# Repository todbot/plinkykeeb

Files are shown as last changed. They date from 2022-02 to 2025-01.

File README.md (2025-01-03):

# plinkykeeb

Simple MIDI controller using KB2040 and computer key switches, in Cherry MX or Kailh Choc versions

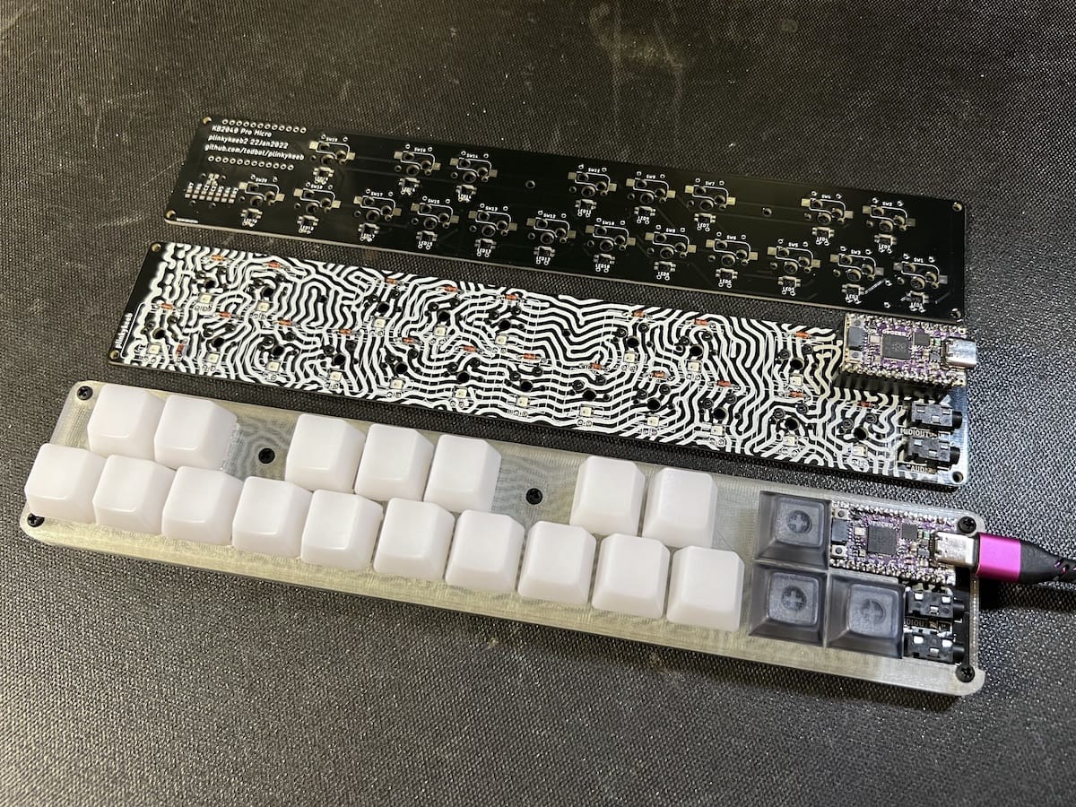
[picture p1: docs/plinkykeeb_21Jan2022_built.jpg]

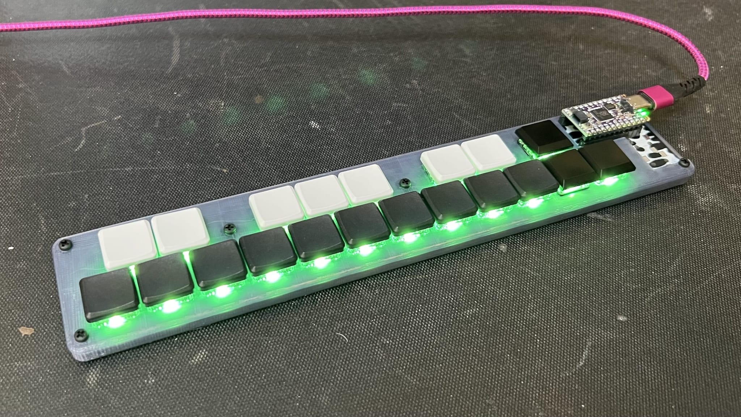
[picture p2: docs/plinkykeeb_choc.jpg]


Also see: https://twitter.com/todbot/status/1492324272714366980__

And this demo video:

https://user-images.githubusercontent.com/274093/153778157-13a1d3d5-e82a-40dc-8635-7ddb3dfab898.mp4

Comparison in heights:
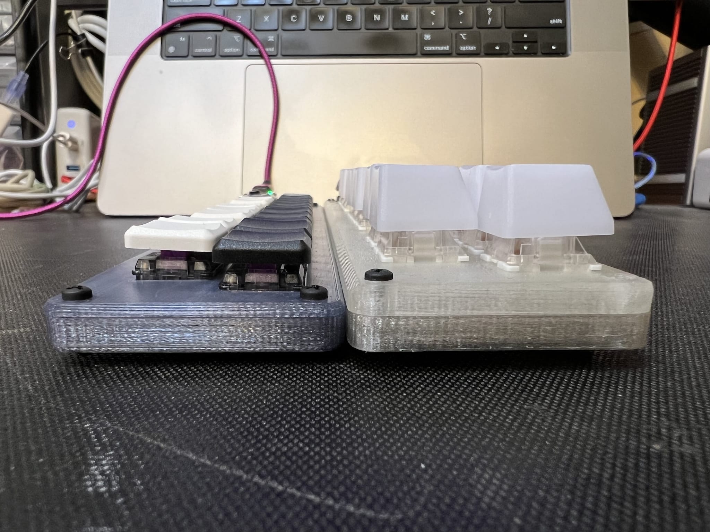
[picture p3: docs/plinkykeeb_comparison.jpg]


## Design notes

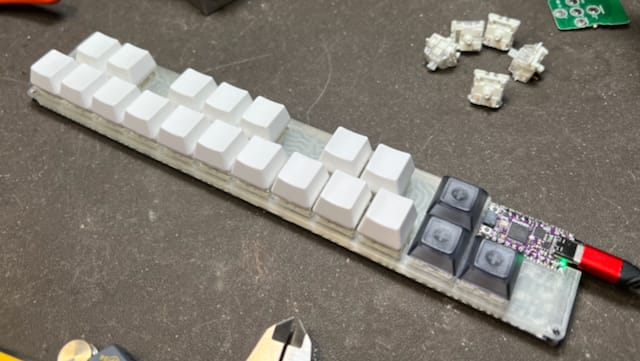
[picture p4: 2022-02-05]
docs/plinkykeeb_21Jan2022.jpg

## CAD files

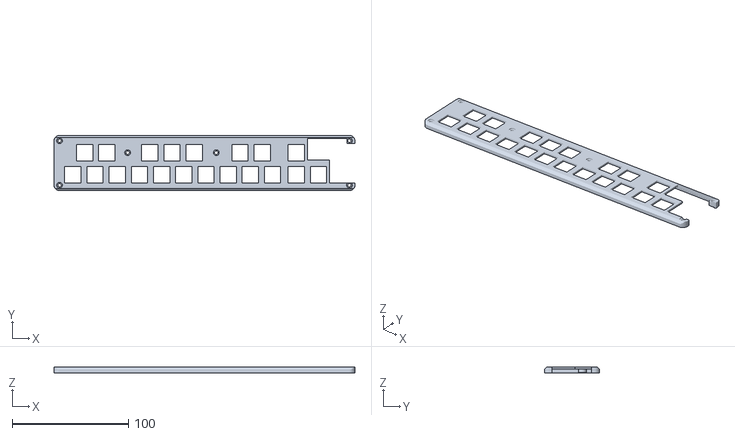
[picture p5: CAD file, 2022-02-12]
hardware/case/plinkykeeb_21Jan2022_top.stl
258.6 x 47.6 x 5.00

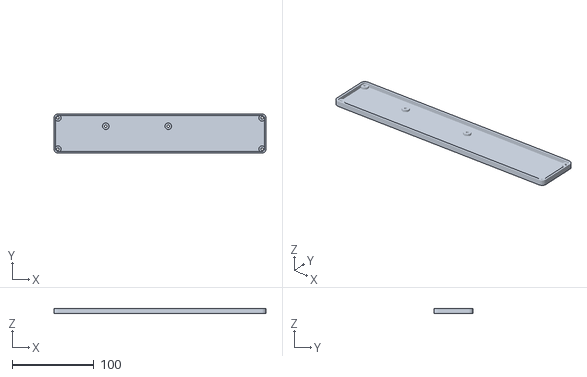
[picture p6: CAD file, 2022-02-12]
hardware/case/plinkykeeb_21Jan2022_bottom.stl
258.6 x 47.6 x 5.60

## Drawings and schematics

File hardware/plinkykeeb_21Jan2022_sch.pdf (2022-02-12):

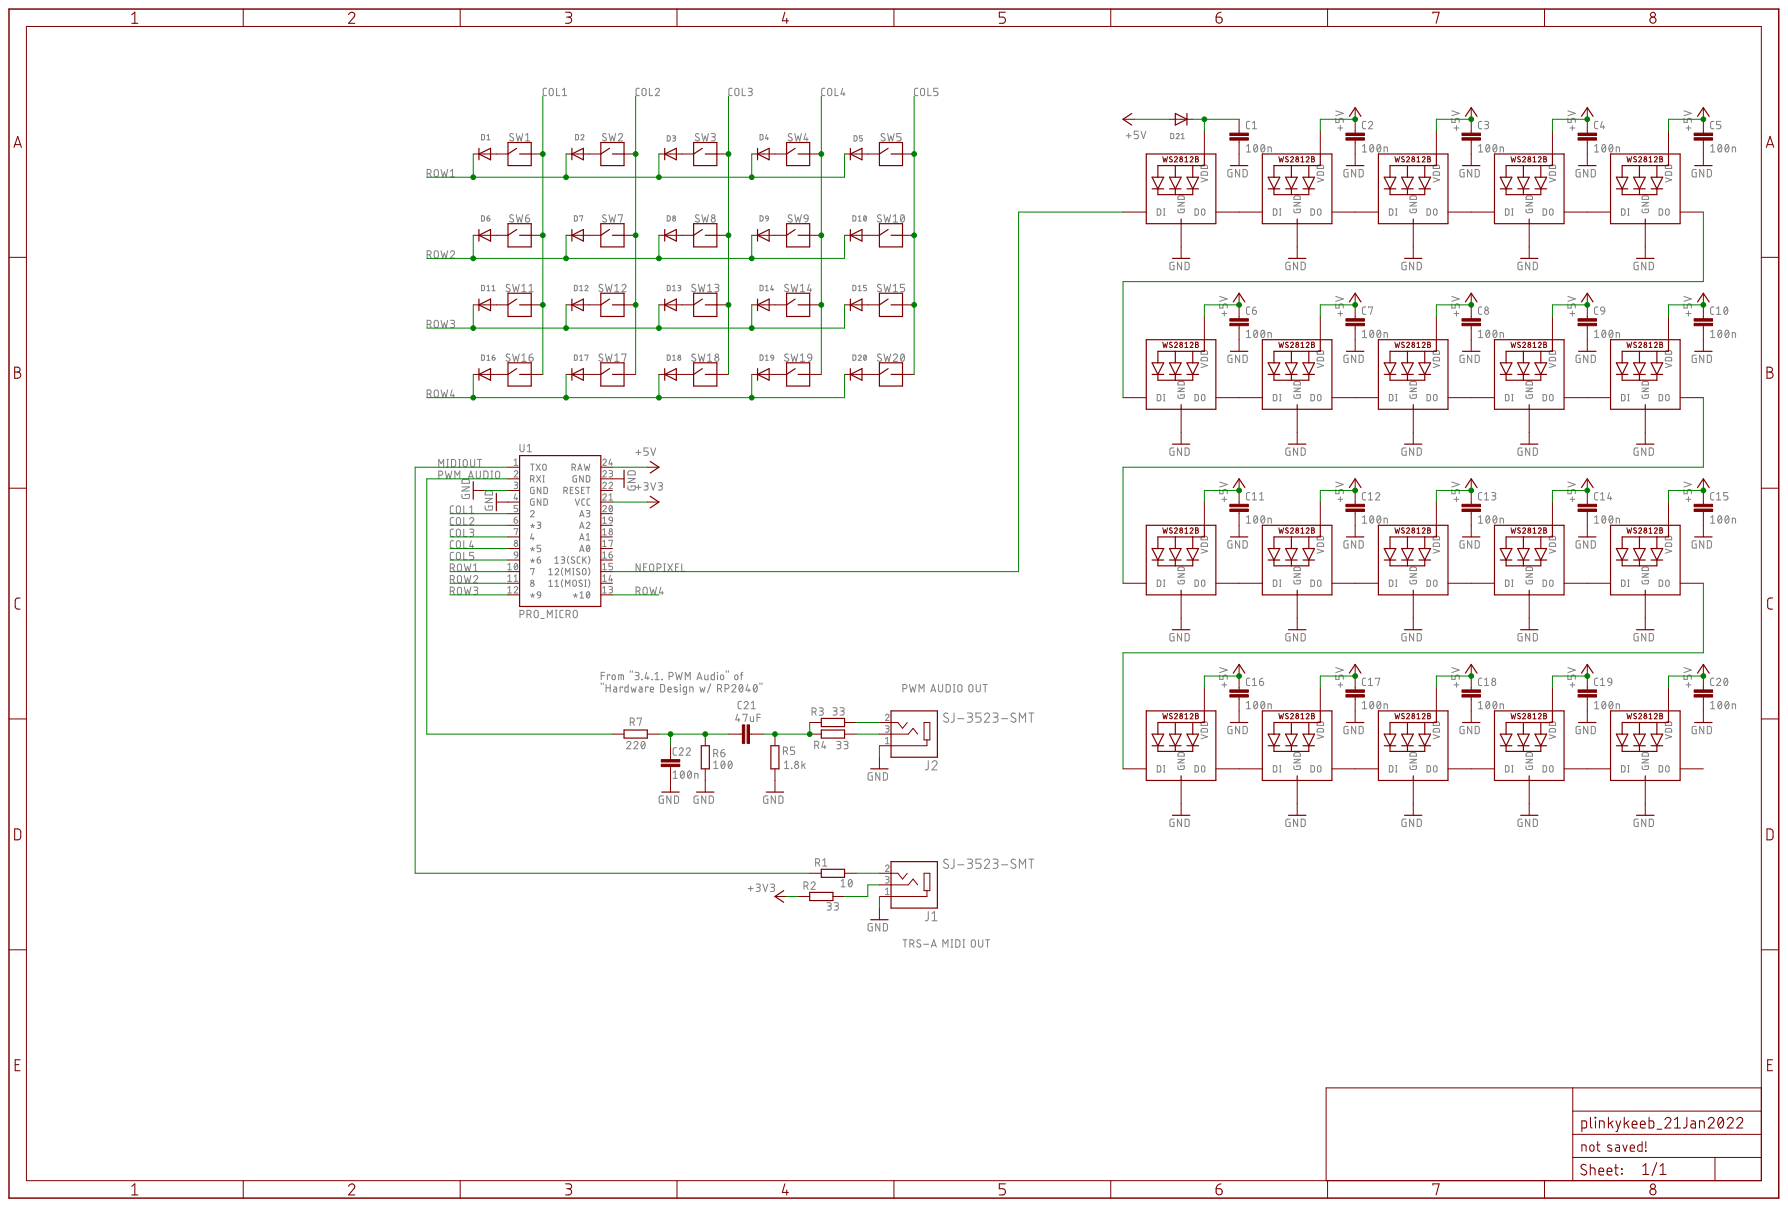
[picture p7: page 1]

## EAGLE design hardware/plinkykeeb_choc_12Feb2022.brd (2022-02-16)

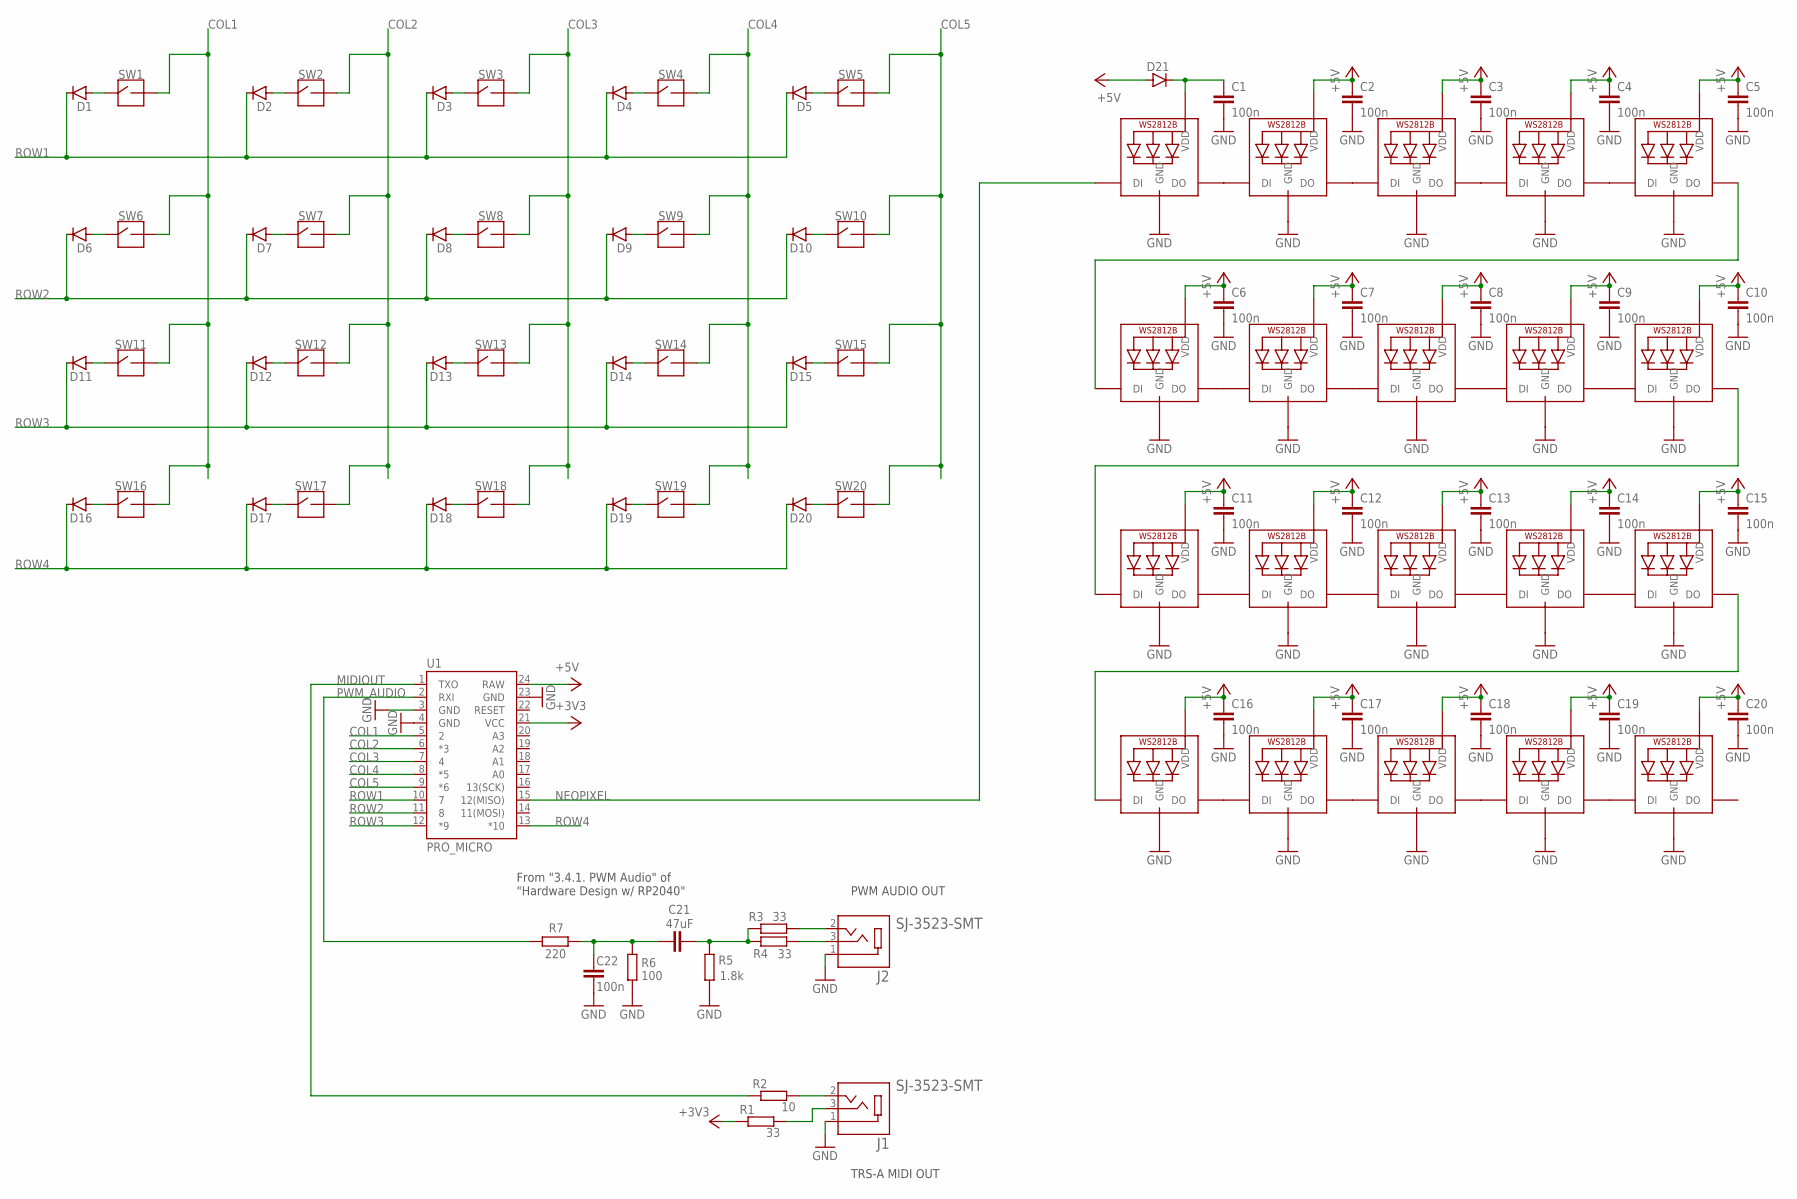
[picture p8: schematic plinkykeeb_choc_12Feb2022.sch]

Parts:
C1, C2, C3, C4, C5, C6, C7, C8, C9, C10, C11, C12, C13, C14, C15, C16, C17, C18, C19, C20, C22: 100n; C0805
C21: 47uF; C0805
D1, D2, D3, D4, D5, D6, D7, D8, D9, D10, D11, D12, D13, D14, D15, D16, D17, D18, D19, D20, D21: D-SOD123; SOD123
J1, J2: SJ-3523-SMT; CUI_SJ-3523-SMT
LED1, LED2, LED3, LED4, LED5, LED6, LED7, LED8, LED9, LED10, LED11, LED12, LED13, LED14, LED15, LED16, LED17, LED18, LED19, LED20: MICROBUILDER_WS2812B_SK6812E; MICROBUILDER_NEO3535_REVERSE
R1, R3, R4: 33; R0805
R2: 10; R0805
R5: 1.8k; R0805
R6: 100; R0805
R7: 220; R0805
SW1, SW2, SW3, SW4, SW5, SW6, SW7, SW8, SW9, SW10, SW11, SW12, SW13, SW14, SW15, SW16, SW17, SW18, SW19, SW20: KBD_SWITCHKALIH_CHOC_SOCKET; KALIH_SOCKET_CHOC
U1: PRO_MICRO; SPARKFUN_PRO_MICRO

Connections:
+3V3: R1.2, U1.21 (VCC)
+5V: C2.1, C3.1, C4.1, C5.1, C6.1, C7.1, C8.1, C9.1, C10.1, C11.1, C12.1, C13.1, C14.1, C15.1, C16.1, C17.1, C18.1, C19.1, C20.1, D21.2 (A), LED2.1-VDD (VDD), LED3.1-VDD (VDD), LED4.1-VDD (VDD), LED5.1-VDD (VDD), LED6.1-VDD (VDD), LED7.1-VDD (VDD), LED8.1-VDD (VDD), LED9.1-VDD (VDD), LED10.1-VDD (VDD), LED11.1-VDD (VDD), LED12.1-VDD (VDD), LED13.1-VDD (VDD), LED14.1-VDD (VDD), LED15.1-VDD (VDD), LED16.1-VDD (VDD), LED17.1-VDD (VDD), LED18.1-VDD (VDD), LED19.1-VDD (VDD), LED20.1-VDD (VDD), U1.24 (RAW)
COL1: SW1.2, SW6.2, SW11.2, SW16.2, U1.5 (2)
COL2: SW2.2, SW7.2, SW12.2, SW17.2, U1.6 (*3)
COL3: SW3.2, SW8.2, SW13.2, SW18.2, U1.7 (4)
COL4: SW4.2, SW9.2, SW14.2, SW19.2, U1.8 (*5)
COL5: SW5.2, SW10.2, SW15.2, SW20.2, U1.9 (*6)
GND: C1.2, C2.2, C3.2, C4.2, C5.2, C6.2, C7.2, C8.2, C9.2, C10.2, C11.2, C12.2, C13.2, C14.2, C15.2, C16.2, C17.2, C18.2, C19.2, C20.2, C22.2, J1.1, J2.1, LED1.3-GND (GND), LED2.3-GND (GND), LED3.3-GND (GND), LED4.3-GND (GND), LED5.3-GND (GND), LED6.3-GND (GND), LED7.3-GND (GND), LED8.3-GND (GND), LED9.3-GND (GND), LED10.3-GND (GND), LED11.3-GND (GND), LED12.3-GND (GND), LED13.3-GND (GND), LED14.3-GND (GND), LED15.3-GND (GND), LED16.3-GND (GND), LED17.3-GND (GND), LED18.3-GND (GND), LED19.3-GND (GND), LED20.3-GND (GND), R5.2, R6.1, U1.3 (GND), U1.4 (GND), U1.23 (GND)
MIDIOUT: R2.2, U1.1 (TXO)
unnamed: LED1.2-DOUT (DO), LED2.4-DIN (DI)
unnamed: LED2.2-DOUT (DO), LED3.4-DIN (DI)
unnamed: LED3.2-DOUT (DO), LED4.4-DIN (DI)
unnamed: LED4.2-DOUT (DO), LED5.4-DIN (DI)
unnamed: LED5.2-DOUT (DO), LED6.4-DIN (DI)
unnamed: D1.2 (A), SW1.1
unnamed: D2.2 (A), SW2.1
unnamed: D3.2 (A), SW3.1
unnamed: D4.2 (A), SW4.1
unnamed: D5.2 (A), SW5.1
unnamed: C1.1, D21.1 (C), LED1.1-VDD (VDD)
unnamed: D6.2 (A), SW6.1
unnamed: D18.2 (A), SW18.1
unnamed: D8.2 (A), SW8.1
unnamed: D9.2 (A), SW9.1
unnamed: D10.2 (A), SW10.1
unnamed: D11.2 (A), SW11.1
unnamed: D12.2 (A), SW12.1
unnamed: D13.2 (A), SW13.1
unnamed: D14.2 (A), SW14.1
unnamed: D15.2 (A), SW15.1
unnamed: D16.2 (A), SW16.1
unnamed: D17.2 (A), SW17.1
unnamed: D19.2 (A), SW19.1
unnamed: D20.2 (A), SW20.1
unnamed: LED7.2-DOUT (DO), LED8.4-DIN (DI)
unnamed: LED8.2-DOUT (DO), LED9.4-DIN (DI)
unnamed: LED9.2-DOUT (DO), LED10.4-DIN (DI)
unnamed: LED10.2-DOUT (DO), LED11.4-DIN (DI)
unnamed: LED11.2-DOUT (DO), LED12.4-DIN (DI)
unnamed: LED6.2-DOUT (DO), LED7.4-DIN (DI)
unnamed: D7.2 (A), SW7.1
unnamed: LED13.2-DOUT (DO), LED14.4-DIN (DI)
unnamed: LED14.2-DOUT (DO), LED15.4-DIN (DI)
unnamed: LED15.2-DOUT (DO), LED16.4-DIN (DI)
unnamed: LED16.2-DOUT (DO), LED17.4-DIN (DI)
unnamed: LED17.2-DOUT (DO), LED18.4-DIN (DI)
unnamed: LED12.2-DOUT (DO), LED13.4-DIN (DI)
unnamed: LED19.2-DOUT (DO), LED20.4-DIN (DI)
unnamed: LED18.2-DOUT (DO), LED19.4-DIN (DI)
unnamed: J1.2, R2.1
unnamed: J1.3, R1.1
unnamed: J2.2, R3.1
unnamed: J2.3, R4.1
unnamed: C21.2, R3.2, R4.2, R5.1
unnamed: C21.1, C22.1, R6.2, R7.1
NEOPIXEL: LED1.4-DIN (DI), U1.15 (12(MISO))
PWM_AUDIO: R7.2, U1.2 (RXI)
ROW1: D1.1 (C), D2.1 (C), D3.1 (C), D4.1 (C), D5.1 (C), U1.10 (7)
ROW2: D6.1 (C), D7.1 (C), D8.1 (C), D9.1 (C), D10.1 (C), U1.11 (8)
ROW3: D11.1 (C), D12.1 (C), D13.1 (C), D14.1 (C), D15.1 (C), U1.12 (*9)
ROW4: D16.1 (C), D17.1 (C), D18.1 (C), D19.1 (C), D20.1 (C), U1.13 (*10)

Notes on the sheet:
From "3.4.1. PWM Audio" of "Hardware Design w/ RP2040"
PWM AUDIO OUT
TRS-A MIDI OUT

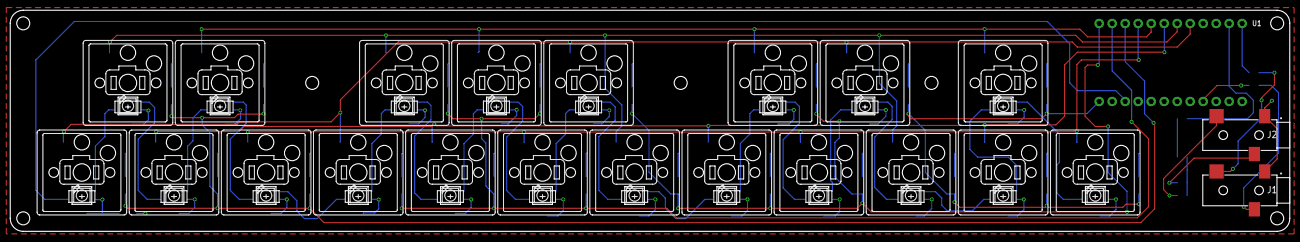
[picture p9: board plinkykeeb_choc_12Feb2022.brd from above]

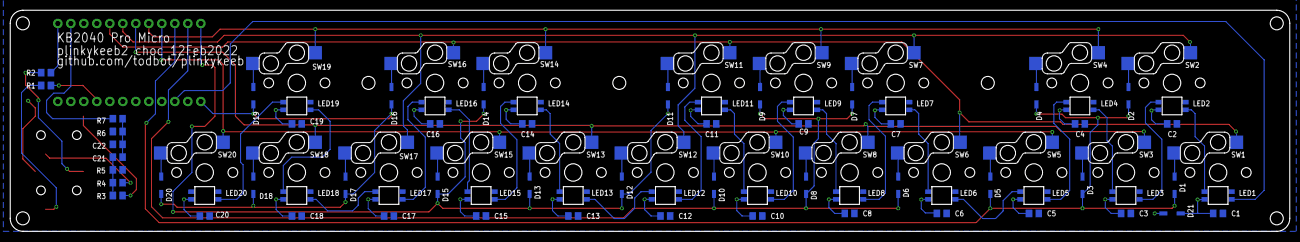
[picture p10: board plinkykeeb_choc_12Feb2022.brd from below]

Board: 2 copper layers, 250.0 x 43.2 mm, 93 parts (50 on the bottom side), 61 nets.

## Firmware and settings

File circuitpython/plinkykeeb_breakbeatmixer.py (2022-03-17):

# plinkykeeb_breakbeatmixer.py -- use CircuitPython mixer level to remix amen break
# 16 Mar 2022 - @todbot / Tod Kurt, from @jedgarparks' idea
#
# Uses pin defs from plinkykeeb but will work on other RP2040 CircuitPython boards
#
import time
import board
import keypad
import busio
import neopixel
import rainbowio

import audiocore
import audiomixer
from audiopwmio import PWMAudioOut as AudioOut

time.sleep(3)

wav_files = (
    'wav/amen_4bar_22k16b.wav', # 137.72 bpm
    'wav/amen_bitA_22k16b.wav',
    'wav/amen_bitB_22k16b.wav',
    'wav/amen_bitC_22k16b.wav',
    'wav/amen_bitD_22k16b.wav',
    'wav/amen_bitE_22k16b.wav',
    'wav/amen_bitF_22k16b.wav',
)
num_voices = len(wav_files)

leds = neopixel.NeoPixel(board.MISO, 20, brightness=0.2, auto_write=True)

row_pins = (board.D7, board.D8, board.D9, board.D10)
col_pins = (board.D2, board.D3, board.D4, board.D5, board.D6)

km = keypad.KeyMatrix( row_pins=row_pins, column_pins=col_pins )

audio = AudioOut( board.RX )
mixer = audiomixer.Mixer(voice_count=num_voices, sample_rate=22050, channel_count=1,
                         bits_per_sample=16, samples_signed=True)
audio.play(mixer) # attach mixer to audio playback

for i in range(num_voices):  # test start all samples at once for use w handle_mixer
    print("loading wav:", wav_files[i])
    wave = audiocore.WaveFile(open(wav_files[i],"rb"))
    mixer.voice[i].play(wave, loop=True)
    mixer.voice[i].level = 0

def handle_mixer(num, pressed):
    voice = mixer.voice[num]   # get mixer voice
    if pressed:
        voice.level = 1.0
    else: # released
        voice.level = 0

print("running")

while True:
    leds.fill( rainbowio.colorwheel( int(time.monotonic() * 20) ) )
    
    event = km.events.get()

    if event:
        print("key:%d %d/%d %d" % (event.key_number, event.pressed, event.released, event.timestamp) )

        if event.key_number < num_voices:
            if event.pressed:
                handle_mixer(event.key_number, True)
            if event.released:
                handle_mixer( event.key_number, False )



######################3

import time
import math
import array
import board
import keypad
import busio
import neopixel
import rainbowio

import audiocore
import audiomixer
from audiopwmio import PWMAudioOut as AudioOut

time.sleep(3)

num_voices = 24

leds = neopixel.NeoPixel(board.MISO, 20, brightness=0.2, auto_write=False)

row_pins = (board.D7, board.D8, board.D9, board.D10)
col_pins = (board.D2, board.D3, board.D4, board.D5, board.D6)

km = keypad.KeyMatrix( row_pins=row_pins, column_pins=col_pins )

audio = AudioOut( board.RX )
mixer = audiomixer.Mixer(voice_count=num_voices, sample_rate=22050, channel_count=1,
                         bits_per_sample=16, samples_signed=False)
audio.play(mixer) # attach mixer to audio playback

freqs = (
                                                65.4064,    69.2957,   73.4162,    77.7817,
    82.4069,   87.3071,   92.4986,   97.9989,   103.8262,   110.0000,  116.5409,   123.4708,
    130.8128,  138.5913,  146.8324,  155.5635,  164.8138,   174.6141,  184.9972,   195.9977,
    207.6523,  220.0000,  233.0819,  246.9417,  261.6256,   277.1826,  293.6648,   311.1270,
    329.6276,  349.2282,  369.9944,  391.9954,  415.3047,   440.0000,
)

tone_volume = 0.5
frequency = 440  # Set this to the Hz of the tone you want to generate.
length = 22050 // frequency
sine_wave = array.array("H", [0] * length)

for i in range(length):
    sine_wave[i] = int((1 + math.sin(math.pi * 2 * i / length)) * tone_volume * (2 ** 15 - 1))

sine_wave_sample = audiocore.RawSample(sine_wave, sample_rate=22050)

#mixer.voice[0].play(sine_wave_sample, loop=True)

def millis(): return time.monotonic()*1000

print("ready!")

decaying = False

while True:
    now = millis()

    if decaying:
        l = mixer.voice[0].level
        if l == 0:
            decaying = False
        else:
            mixer.voice[0].level = max(l - 0.001, 0)

    while km.events:
        event = km.events.get()
        print("key:%d %d/%d %d" % (event.key_number, event.pressed, event.released, event.timestamp) )
        if event.pressed:
            pass
        if event.released:
            pass
        
    # event = km.events.get()
    # if event:
    #     print("key:%d %d/%d %d" % (event.key_number, event.pressed, event.released, event.timestamp) )
    #     if event.pressed:
    #         #mixer.voice[ 0 ].level = 1.0
    #     if event.released:
    #         decaying = True
    #         #mixer.voice[ 0 ].level = 0.0







# plinkykeeb_midiout.py - send MIDI out via USB or serial
#
# 4 Feb 2022 - @todbot / Tod Kurt - https://github.com/todbot/plinkykeeb
#

print("plinkykeeb_midiout!")

import time
import board
import keypad
import busio
import neopixel
import rainbowio
import usb_midi
import adafruit_midi
from adafruit_midi.note_on import NoteOn
from adafruit_midi.pitch_bend import PitchBend

# config
octave = 3
note_velocity = 127

leds = neopixel.NeoPixel(board.MISO, 20, brightness=0.2, auto_write=False)

midi_uart = busio.UART(tx=board.TX, rx=None, baudrate=31250 ) # timeout=0.01)
midi_serial = adafruit_midi.MIDI(midi_out=midi_uart)
midi_usb = adafruit_midi.MIDI( midi_in=usb_midi.ports[0],
                               midi_out=usb_midi.ports[1] )

row_pins = (board.D7, board.D8, board.D9, board.D10)
col_pins = (board.D2, board.D3, board.D4, board.D5, board.D6)

km = keypad.KeyMatrix( row_pins=row_pins, column_pins=col_pins )

# I like millis
def millis(): return time.monotonic()*1000

# scale a value by amount/256, expects an int, returns an int
def scale8(val,amount):
    return (val*amount)//256
# dim all leds by an (amount/256)
def dim_leds_by(leds, amount):
    leds[0:] = [[max(scale8(i,amount),0) for i in l] for l in leds]

spin_hue = False
oct_switch = False

led_last_update_millis = 0
led_millis = 5

keys_pressed = []  # list of keys currently being pressed down

while True:
    now = millis()
    
    # update the LEDs, but only if keys pressed
    if now - led_last_update_millis > led_millis:
        led_last_update_millis = now
        for i in keys_pressed:  # light up those keys that are pressed
            leds[ i ] = rainbowio.colorwheel( int(time.monotonic() * 20) )
        dim_leds_by(leds, 250)  # fade everyone out slowly
        leds.show()

    if spin_hue:
        hue = (time.monotonic() * 100 ) % 256
        leds.fill( rainbowio.colorwheel( int(hue) ) )

    event = km.events.get()
    if event:
        print("key:%d %d/%d %d" % (event.key_number, event.pressed, event.released, event.timestamp) )
        #print("\t\t", dir(event))
        
        if event.key_number < 17:
            note_base = octave * 12
            note_val = event.key_number + note_base
            
            if event.pressed:
                noteon = NoteOn(note_val, note_velocity)
                print("note on:",note_val)
                midi_serial.send( noteon )
                midi_usb.send( noteon )
                leds[ event.key_number ] = rainbowio.colorwheel( time.monotonic() * 20 )
                keys_pressed.append( event.key_number )
                
            if event.released:
                noteoff = NoteOn(note_val, 0)
                midi_serial.send( noteoff )
                midi_usb.send( noteoff )
                keys_pressed.remove( event.key_number )
        else:
            spin_hue = event.pressed
            if event.key_number == 19: # octave up/dn enable
                oct_switch = event.pressed

            # this is dumb, pitch up should be +8191, pitch middle 0, pitch down -8192
            
            if event.key_number == 18: # pitchbend up
                if event.pressed and oct_switch:
                    octave = octave+1
                else:
                    pb_val = PitchBend(16383) if event.pressed else PitchBend(8192)
                    midi_serial.send( pb_val )
                    midi_usb.send( pb_val )
            if event.key_number == 17: # pitchbend down
                if event.pressed and oct_switch:
                    octave = octave-1
                else:
                    pb_val = PitchBend(0) if event.pressed else PitchBend(8192)
                    midi_serial.send( pb_val )
                    midi_usb.send( pb_val )

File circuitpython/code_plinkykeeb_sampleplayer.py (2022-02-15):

# plinkykeeb_sampleplayer.py - play multiple samples concurrently, some looped, some not
#
# 5 Feb 2022 - @todbot / Tod Kurt - https://github.com/todbot/plinkykeeb
#
# Copy this file as "code.py" to your CIRCUITPY drive
# Install "neopixel" library with "circup install neopixel"
#
# Convert files to appropriate WAV format (mono, 22050 Hz, 16-bit signed) with command:
#  sox loop.mp3 -b 16 -c 1 -r 22050 loop.wav
# or try:
#  ffmpeg -i loop.mp3 -ac 1 -ar 22050 loop.wav  (but I think this needs codec spec'd
#

print("plinkykeeb_sampleplayer!")

import time
import board
import keypad
import neopixel
import rainbowio
import supervisor

import audiocore
import audiomixer
from audiopwmio import PWMAudioOut as AudioOut

# map key number to wave file
# a list of which samples to play on which keys,
# and if the sample should loop or not
# if a key has no sample, use (None,None)
wav_files = (
    # filename,           loop?
    ('wav/909kick4.wav', False),        # C
    ('wav/909clap1.wav', False),        # C#
    ('wav/909snare2.wav', False),       # D
    ('wav/909cym2.wav', False),         # D#
    (None, None),                       # E
    (None, None),                       # F
    ('wav/909hatclosed2.wav', False),   # F#
    (None, None),                       # G
    ('wav/909hatopen5.wav', False),     # G#
    (None, None),                       # A
    (None, None),                       # A#
    (None, None),                       # B
    ('wav/amenfull_22k_s16.wav', True), # C
    ('wav/amen1_22k_s16.wav', True),    # C#
    ('wav/ohohoh2.wav', True),          # D
    ('wav/amen2_22k_s16.wav', True),    # D#
    (None, None),                       # E
)

leds = neopixel.NeoPixel(board.MISO, 20, brightness=0.2, auto_write=False)

# wait a little bit, with a light show
# so USB can stabilize and not garble & glitch audio
for i in range(0,300):
    leds.fill( rainbowio.colorwheel(i) );
    leds.show()
    time.sleep(0.01)
print("ready to go!")

# pins used by keyboard
row_pins = (board.D7, board.D8, board.D9, board.D10)
col_pins = (board.D2, board.D3, board.D4, board.D5, board.D6)

km = keypad.KeyMatrix( row_pins=row_pins, column_pins=col_pins )

audio = AudioOut( board.RX )
mixer = audiomixer.Mixer(voice_count=len(wav_files), sample_rate=22050, channel_count=1,
                         bits_per_sample=16, samples_signed=True)
audio.play(mixer) # attach mixer to audio playback

# # load all the wavs into RAM
# wavs = [None] * len(wav_files)
# for i in range(len(wavs)):
#     (wav_file, loopit) = wav_files[i]
#     if wav_file is not None:
#         wavs[i] = audiocore.WaveFile(open(wav_file,"rb"))

# # play or stop a RAM WAV sample using the mixer
# def handle_sample_wavs(num, pressed):
#     voice = mixer.voice[num]   # get mixer voice
#     (wav_file, loopit) = wav_files[num]
#     if pressed:
#         if wav_file is not None:
#             voice.play(wavs[num],loop=loopit)
#     else: # released
#         if loopit:
#             voice.stop()  # only stop looping samples, others one-shot

# play or stop a sample using the mixer
def handle_sample(num, pressed):
    voice = mixer.voice[num]   # get mixer voice
    (wav_file, loopit) = wav_files[num]
    if pressed:
        if wav_file is not None:
            wave = audiocore.WaveFile(open(wav_file,"rb"))
            voice.play(wave,loop=loopit)
    else: # released
        if loopit:
            voice.stop()  # only stop looping samples, others one-shot


# I like millis
def millis(): return supervisor.ticks_ms()

# scale a value by amount/256, expects an int, returns an int
def scale8(val,amount):
    return (val*amount)//256
# dim all leds by an (amount/256)
def dim_leds_by(leds, amount):
    leds[0:] = [[max(scale8(i,amount),0) for i in l] for l in leds]

leds.fill(0x333333)

led_last_update_millis = 0
led_millis = 5

keys_pressed = []  # list of keys currently being pressed down
while True:
    now = millis()

    # update the LEDs, but only if keys pressed
    if now - led_last_update_millis > led_millis:
        led_last_update_millis = now
        for i in keys_pressed:  # light up those keys that are pressed
            leds[ i ] = rainbowio.colorwheel( int(time.monotonic() * 20) )
        dim_leds_by(leds, 250)  # fade everyone out slowly
        leds.show()

    event = km.events.get()

    if event:
        print("key:%d %d/%d %d" % (event.key_number, event.pressed, event.released, event.timestamp) )

        if event.key_number < len(wav_files):
            if event.pressed:
                handle_sample( event.key_number, True )
                keys_pressed.append( event.key_number )

            if event.released:
                handle_sample( event.key_number, False )
                keys_pressed.remove( event.key_number )

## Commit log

2022-01-24 rejiggered audio out
    [plinkykeeb2_21Jan2022.brd, plinkykeeb2_21Jan2022.sch]
2022-01-24 fix name
    [plinkykeeb_21Jan2022.brd, plinkykeeb_21Jan2022.sch]
2022-01-25 shrink pcb a bit so parts can be 3dprinted
    [plinkykeeb_21Jan2022.brd]
2022-01-26 submitted to pcbway
    [plinkykeeb_21Jan2022.brd, plinkykeeb_21Jan2022.sch]
2022-02-08 checked in arduino test
2022-02-08 arduino midi_test added
2022-02-12 updated case
    [plinkykeeb_21Jan2022_bottom.stl, plinkykeeb_21Jan2022_top.stl]
2022-02-13 pontential choc version, a little smaller!
    [plinkykeeb_choc_12Feb2022.brd, plinkykeeb_choc_12Feb2022.sch]
2022-02-14 some new sampleplayer thoughts
2022-02-15 circpy sampleplayer updates
2022-02-15 choc updates
    [plinkykeeb_choc_12Feb2022.brd, plinkykeeb_choc_12Feb2022.sch]
2022-02-16 plinkykeeb_choc_12Feb sent to fab
    [plinkykeeb_choc_12Feb2022.brd]
2022-02-16 update midiout.py to keep LED on while key pressed
2022-02-24 mozzi_test: LEDs go to core1 because they are naughty

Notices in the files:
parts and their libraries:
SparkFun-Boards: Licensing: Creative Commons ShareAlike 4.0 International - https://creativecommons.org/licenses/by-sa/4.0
